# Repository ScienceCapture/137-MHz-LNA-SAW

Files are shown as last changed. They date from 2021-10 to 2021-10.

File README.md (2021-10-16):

# 137-MHz-LNA-SAW

By using a simple double-crossed or QFH antenna it is possible to detect and record the transmission of the NOAA and Meteor-M2 weather satellites. This signal can be received and then decoded into a detailed image of the Earth taken from space! Its quality however, is directly determined by the signal strength. This is where the 137-MHz-LNA-SAW comes into play! The integrated low noise amplifier (LNA) makes the weak signal much stronger. It is then passed through the SAW filter with attenuates all of the unwanted frequencies with a steep cutoff region. The device was designed with ESD safety in mind and features a USB-C port to power the amplifier.

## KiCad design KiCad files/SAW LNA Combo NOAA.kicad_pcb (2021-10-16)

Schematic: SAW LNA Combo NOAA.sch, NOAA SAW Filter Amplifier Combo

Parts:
C1, C3, C4, C5: 96pF; C_0805_2012Metric
C2: 96nF; C_0805_2012Metric
C6: 10pF; C_0805_2012Metric
C7, C9: 1uF; C_0805_2012Metric
C8: 100uF; CP_Elec_6.3x5.8
D1, D2, D3: D_TVS; D_0201_0603Metric
D4: LED; LED_0805_2012Metric
J1, J2: Conn_Coaxial; SMA_Amphenol_132289_EdgeMount
L1, L2, L4: 14nH; L_0402_1005Metric
L3: 1.4uH; L_1008_2520Metric_Pad1.43x2.20mm_HandSolder
P1: USB_C_Plug_USB2.0; USB_C_Receptacle_Amphenol_12401610E4-2A
R1: 350R; R_0603_1608Metric
U1: ZLDO500; SO-8_5.3x6.2mm_P1.27mm
U2: SPF5189Z; SOT-89-3
U3: SF2059B-1

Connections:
+5V: C5.2, L3.1, L4.2
GND: C2.1, C3.1, C5.1, C7.1, C8.2, C9.1, D1.2 (A2), D2.2 (A2), D3.2 (A2), D4.1 (K), J1.2 (Ext), J2.2 (Ext), P1.A1 (GND), P1.A12 (GND), P1.B1 (GND), P1.B12 (GND), P1.S1 (SHIELD), U1.2, U1.7, U2.2 (GND), U3.1, U3.2, U3.3, U3.4, U3.6, U3.7, U3.8, U3.9; also elsewhere on the board
unnamed: C1.1, L1.1
unnamed: C1.2, D1.1 (A1), J1.1 (In)
unnamed 4: C2.2, C8.1, C9.2, D2.1 (A1), P1.A4 (VBUS), P1.A9 (VBUS), P1.B4 (VBUS), P1.B9 (VBUS), R1.1, U1.3; also elsewhere on the board
unnamed: C3.2, L2.2, L4.1
unnamed: C4.1, U3.10
unnamed: C4.2, L3.2, U2.3
unnamed: C6.1, C7.2, L2.1, U1.5
unnamed: C6.2, U1.8
unnamed: D3.1 (A1), J2.1 (In), U3.5
unnamed: D4.2 (A), R1.2
unnamed: L1.2, U2.1

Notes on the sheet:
Rainbow happy vibes
3671333 Wurth Elektronik Shield

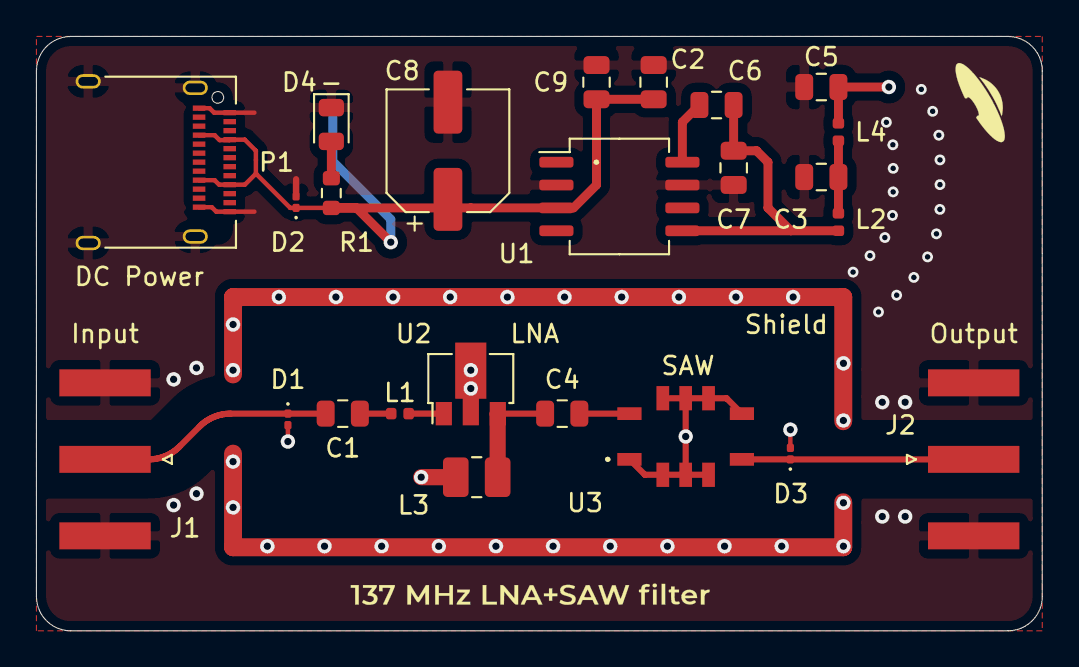
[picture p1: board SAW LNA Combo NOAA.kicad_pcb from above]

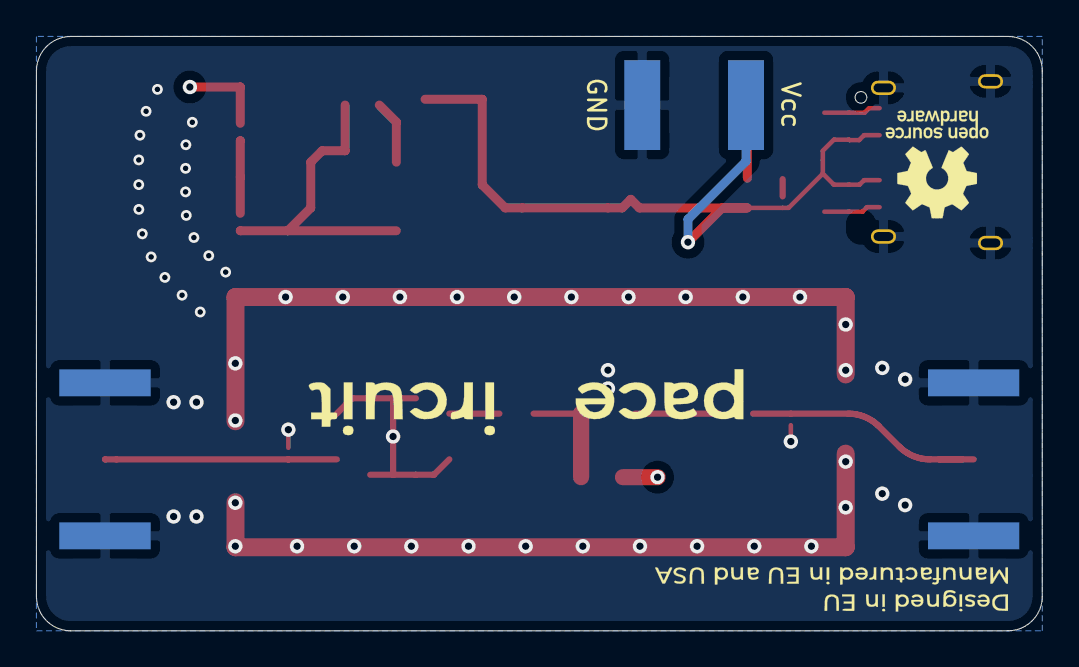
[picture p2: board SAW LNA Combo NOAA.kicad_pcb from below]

Board: 4 copper layers, 55.9 x 33.0 mm, 27 parts (2 on the bottom side), 13 nets.

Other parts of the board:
GND: Pad_small
Shield: RF_Guard_Ring_SAW_NOAA
Vcc: Pad_small

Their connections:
GND: GND.1; also elsewhere on the board
unnamed 4: Vcc.1; also elsewhere on the board
